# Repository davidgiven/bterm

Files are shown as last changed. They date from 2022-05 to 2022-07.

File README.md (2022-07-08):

bterm
=====

What?
-----

This is a set of firmware and hardware to turn a Brother WP-1 into a serial
terminal for a Raspberry Pi.

It consists of:

  - software to make a Brother bootable floppy containing a VT102-subset serial
	terminal

  - firmware for a PSoC5 CY8CKIT-049 based interface

  - a PCB which connects the Brother, CY8CKIT-049 and Raspberry Pi together

  - a 3D printable fascia which fits into the Brother's expansion slot

It also provides a MDA/Hercules/CGA-compatible video out connector which
reproduces what's on the Brother's screen.

Why?
----

Why not?

How?
----

So this is all so bespoke to my purposes that it's probably not going to be
very useful to anyone else. What documentation there is comes from the Youtube
series of videos I made while I developed this:

https://www.youtube.com/playlist?list=PLuQ2s_IbSWv5NDpc9Ew3BYDSF7siX9mNj

But here are some quick notes:

  - build the client software are write it to a floppy (you'll need zmac, ld80
	and fluxengine)

  - build the CY8CKIT-049 firmware and flash it with the Cypress development
	tools

  - get the PCB made and solder the connectors onto it

  - solder a 44-pin connector onto the unpopulated expansion breakout pads on
	the Brother motherboard

  - install Linux (or another OS of your choice) onto a Raspberry Pi, and
	configure out to use hardware handshaking on the main UART

  - plug everything together and attach the flyleads to the Brother CPU's /RD,
	/WR and /IOEN lines

  - ensure that there's a reset button and power switch connected to the
	interface board

  - switch everything on with Code+Q pressed on the Brother

...and then, if you're lucky, it might work.

If you are actually interested in trying this, best thing is to [file an
issue](https://github.com/davidgiven/bterm/issues/new/choose) and I'll see what
I can do to help. Or just send me an email (see below).

Who?
----

I am David Given, a.k.a. hjalfi in various places. Feel free to send me email
at [dg@cowlark.com](mailto:dg@cowlark.com). You may also [like to visit my
website](http://cowlark.com); there may or may not be something interesting
there.

License?
--------

Everything I wrote, which is nearly everything, is freely redistributable under
the terms of the simplified 2-clause BSD license. tl;dr: go nuts, just don't
claim you wrote it. See the `LICENSE` file for more details.

The one exception are the Raspberry Pi and CYC8KIT-049 footprints in the
`kicad-pcb` directory, which are by SnapEDA and licensed under a Creative
Commons Attribution-ShareAlike 4.0 International License (CC BY-SA) with Design
Exception 1.0. This exception essentially means that the CC BY-SA limitations
don't apply as they're being distributed as part of an aggregate design. [See
SnapEDA's page for
details.](https://support.snapeda.com/en/articles/2957815-what-is-the-design-exception-1-0)

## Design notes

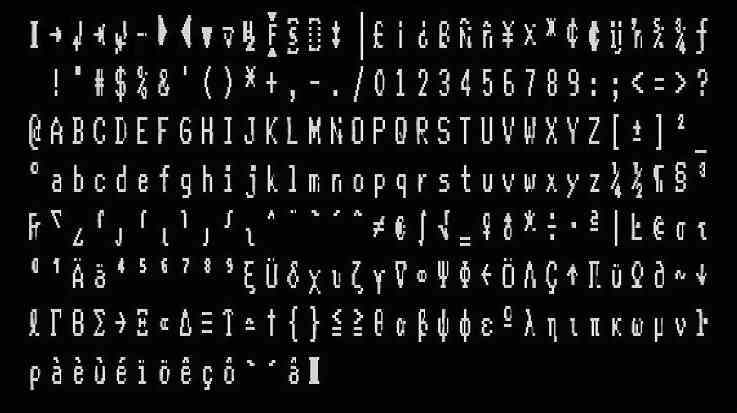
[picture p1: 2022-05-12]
client/font.jpg

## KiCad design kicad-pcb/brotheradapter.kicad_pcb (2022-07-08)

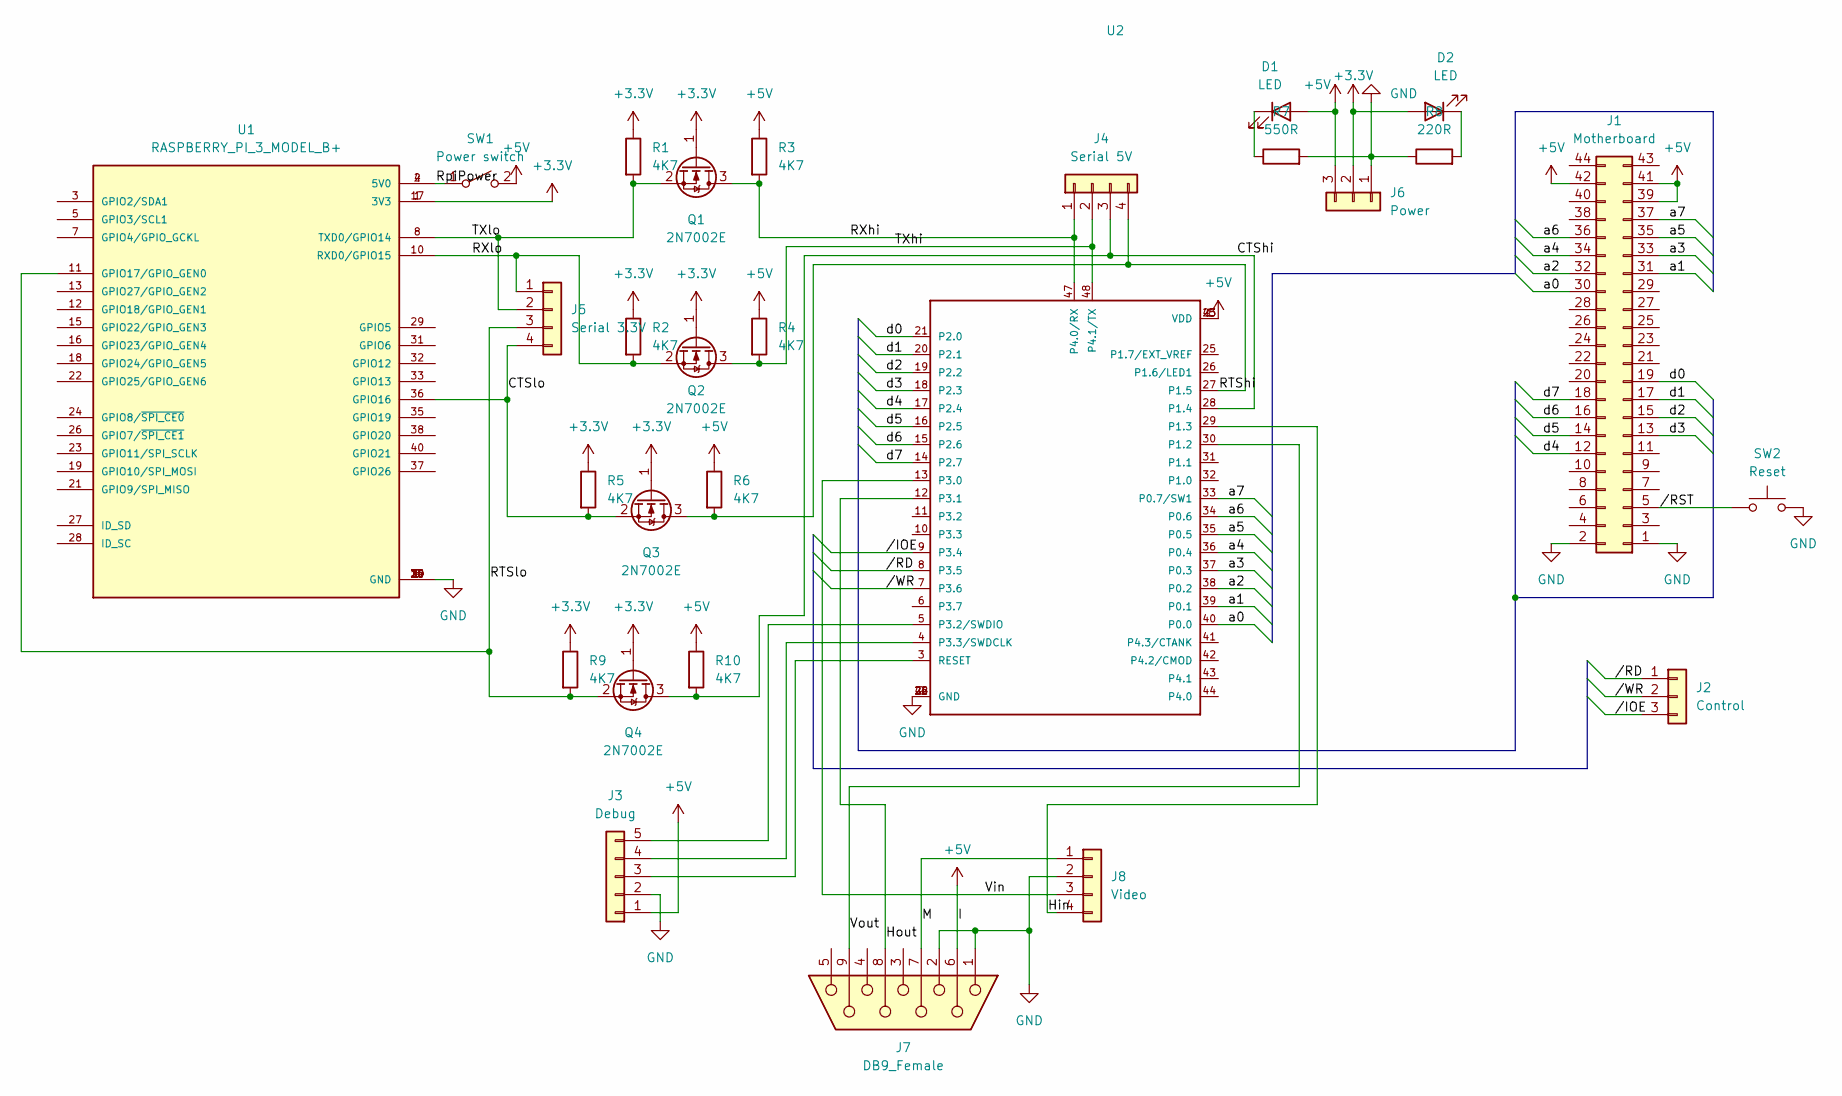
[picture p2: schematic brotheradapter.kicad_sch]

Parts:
D1, D2: LED; LED_0603_1608Metric
J1: Motherboard; PinHeader_2x22_P2.54mm_Vertical
J2: Control; PinSocket_1x03_P2.54mm_Vertical
J3: Debug; PinHeader_1x05_P2.54mm_Vertical
J4: Serial 5V; PinSocket_1x04_P2.54mm_Vertical
J5: Serial 3.3V; PinSocket_1x04_P2.54mm_Vertical
J6: Power; PinSocket_1x03_P2.54mm_Vertical
J7: DB9_Female; DSUB-9_Female_EdgeMount_P2.77mm
J8: Video; PinHeader_1x04_P2.54mm_Vertical
Q1, Q2, Q3, Q4: 2N7002E; SOT-23
R1, R2, R3, R4, R5, R6, R9, R10: 4K7; R_0603_1608Metric
R7: 550R; R_0603_1608Metric
R8: 220R; R_0603_1608Metric
SW1: Power switch; PinHeader_1x02_P2.54mm_Vertical
SW2: Reset; PinHeader_1x02_P2.54mm_Vertical
U1: RASPBERRY_PI_3_MODEL_B+; MODULE_RASPBERRY_PI_3_MODEL_B+; PARTREV 1.0
U2: CY8CKIT-049-42XX

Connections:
+3V3: D2.2 (A), J6.2, Q1.1 (G), Q2.1 (G), Q3.1 (G), Q4.1 (G), R1.1, R2.1, R5.1, R9.1, U1.1 (3V3), U1.17 (3V3)
+5V: D1.2 (A), J1.39, J1.41, J1.42, J3.1, J6.3, J7.6, R3.1, R4.1, R6.1, R10.1, SW1.2 (B), U2.1 (VDD), U2.23 (VDD), U2.45 (VDD)
/CTShi: J4.3, Q4.3 (D), R10.2, U2.28 (P1.4)
/CTSlo: J5.4, Q3.2 (S), R5.2, U1.36 (GPIO16)
/Hin: J8.4, U2.29 (P1.3)
/Hout: J7.8, U2.12 (P3.1)
/M: J7.7, J8.1
/RTSlo: J5.3, Q4.2 (S), R9.2, U1.11 (GPIO17/GPIO_GEN0)
/RXhi: J4.1, Q1.3 (D), R3.2, U2.47 (P4.0/RX)
/RXlo: J5.1, Q2.2 (S), R2.2, U1.10 (RXD0/GPIO15)
/RpiPower: SW1.1 (A), U1.2 (5V0), U1.4 (5V0)
/TXhi: J4.2, Q2.3 (D), R4.2, U2.48 (P4.1/TX)
/TXlo: J5.2, Q1.2 (S), R1.2, U1.8 (TXD0/GPIO14)
/Vin: J8.3, U2.13 (P3.0)
/Vout: J7.9, U2.30 (P1.2)
/a0: J1.30, U2.40 (P0.0)
/a1: J1.31, U2.39 (P0.1)
/a2: J1.32, U2.38 (P0.2)
/a3: J1.33, U2.37 (P0.3)
/a4: J1.34, U2.36 (P0.4)
/a5: J1.35, U2.35 (P0.5)
/a6: J1.36, U2.34 (P0.6)
/a7: J1.37, U2.33 (P0.7/SW1)
/d0: J1.19, U2.21 (P2.0)
/d1: J1.17, U2.20 (P2.1)
/d2: J1.15, U2.19 (P2.2)
/d3: J1.13, U2.18 (P2.3)
/d4: J1.12, U2.17 (P2.4)
/d5: J1.14, U2.16 (P2.5)
/d6: J1.16, U2.15 (P2.6)
/d7: J1.18, U2.14 (P2.7)
//IOE: J2.3, U2.9 (P3.4)
//RD: J2.1, U2.8 (P3.5)
//RST: J1.5, SW2.1
//WR: J2.2, U2.7 (P3.6)
GND: J1.1, J1.2, J3.2, J6.1, J7.1, J7.2, J8.2, R7.2, R8.1, SW2.2, U1.6 (GND), U1.9 (GND), U1.14 (GND), U1.20 (GND), U1.25 (GND), U1.30 (GND), U1.34 (GND), U1.39 (GND), U2.2 (GND), U2.22 (GND), U2.24 (GND), U2.46 (GND)
unnamed: D1.1 (K), R7.1
unnamed: D2.1 (K), R8.2
unnamed: J3.3, U2.3 (RESET)
unnamed: J3.4, U2.4 (P3.3/SWDCLK)
unnamed: J3.5, U2.5 (P3.2/SWDIO)
unnamed: J4.4, Q3.3 (D), R6.2, U2.27 (P1.5)

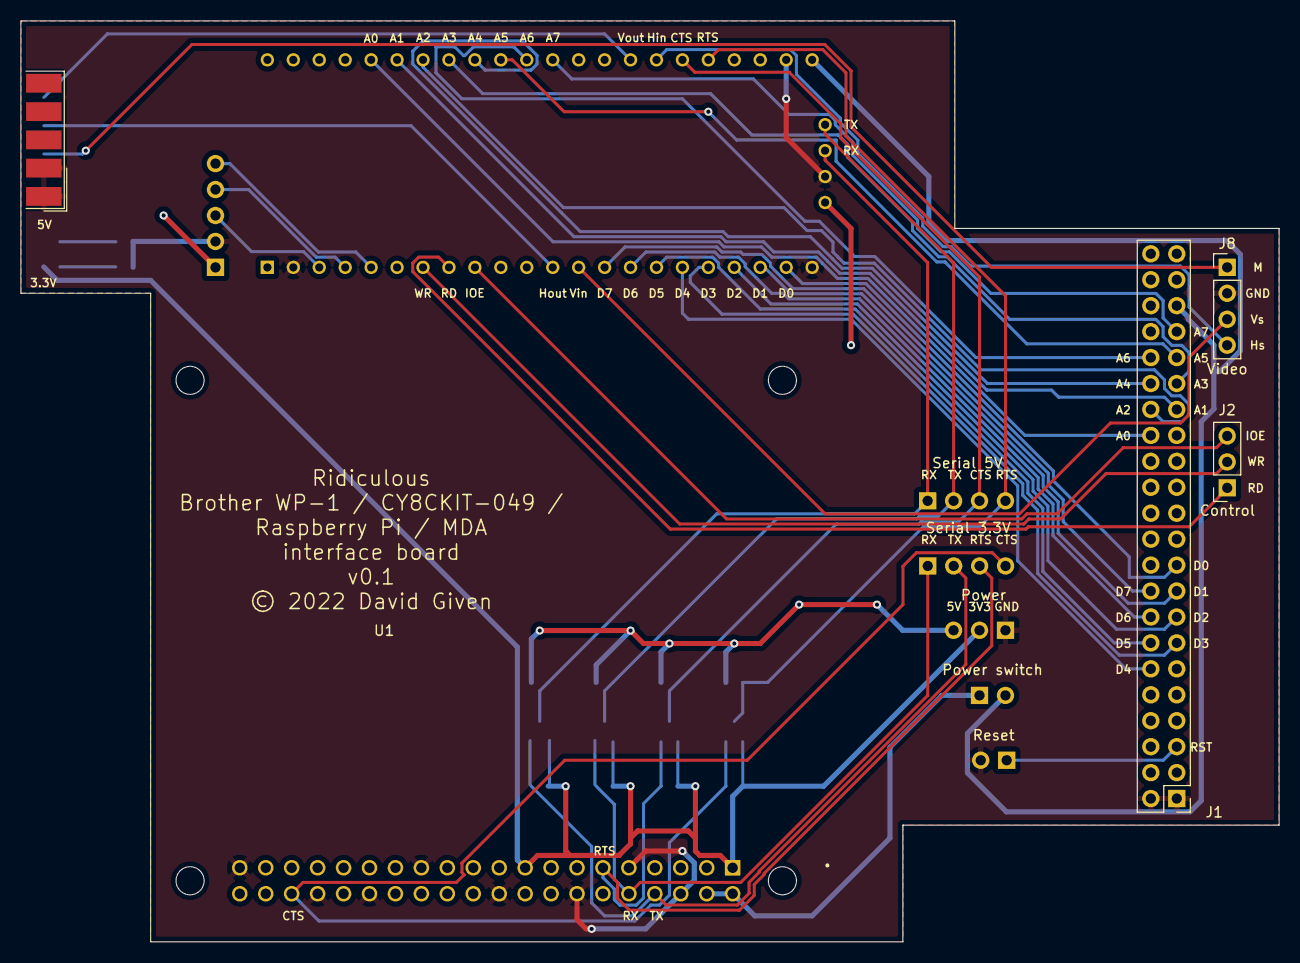
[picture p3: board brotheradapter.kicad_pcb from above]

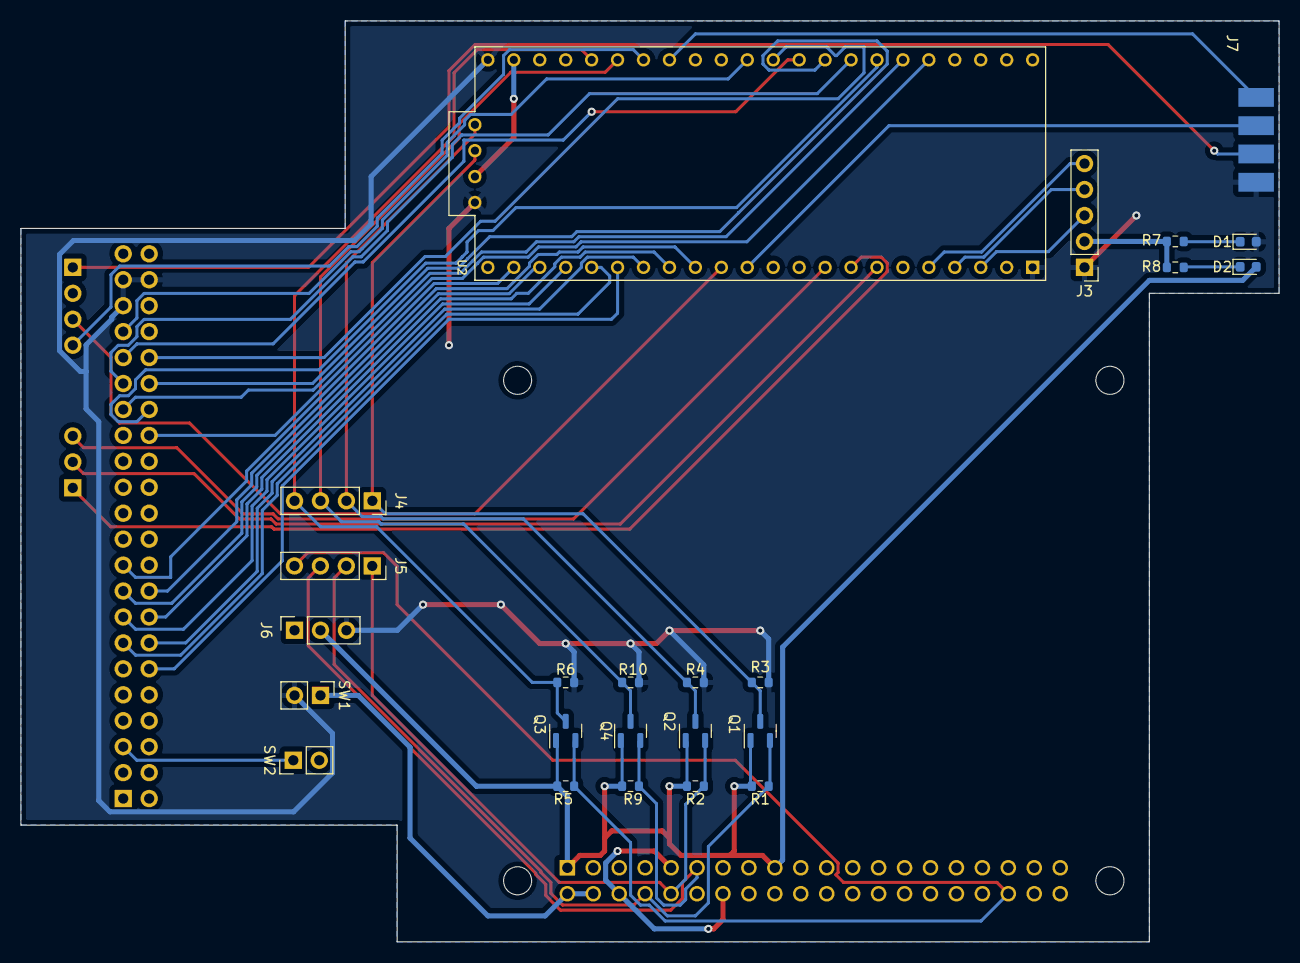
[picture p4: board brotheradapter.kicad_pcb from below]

Board: 2 copper layers, 123.2 x 90.2 mm, 28 parts (23 on the bottom side), 42 nets.

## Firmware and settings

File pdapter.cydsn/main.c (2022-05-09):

#include "project.h"
#include <stdint.h>
#include <stdbool.h>

enum
{
    RS_IDLE = 0, /* no data in buffer, no data pending */
    RS_READABLE, /* data in buffer */
    RS_DONE,     /* data has been read */
};

enum
{
    RA_DATA = (1<<0), /* data has been from buffer */
    RA_DONE = (1<<1), /* interface has been seen in RS_DONE */
};

enum
{
    WS_WRITABLE = 0, /* waiting for data in buffer */
    WS_WRITING,      /* data is being sent */
    WS_DONE,         /* data has been sent */
};

enum
{
    WA_DATA = (1<<2), /* data has been placed in the buffer */
    WA_DONE = (1<<3), /* interface has been seen in WS_DONE */
};

enum
{
    RESET = 128
};

static int read_state = RS_IDLE;
static int write_state = WS_WRITABLE;

int main(void)
{
    CyGlobalIntEnable; /* Enable global interrupts. */
    UART_Start();

    for(;;)
    {
        uint32_t ackbits = STATUS_REG1_Read();
        
        if (ackbits & RESET)
        {
            //UART_UartPutString("reset\r\n");
            read_state = RS_IDLE;
            write_state = WS_WRITABLE;
        }
        
        unsigned readBufferSize = UART_SpiUartGetRxBufferSize();
        switch (read_state)
        {
            case RS_IDLE:
            {
                if (readBufferSize > 0)
                {
                    uint32_t b = UART_UartGetByte();
                    CONTROL_REG0_Write(b & 0xff);
                    read_state = RS_READABLE;
                    //UART_UartPutString("RS_IDLE -> RS_READABLE\r\n");
                }                
                break;
            }
            
            case RS_READABLE:
            {
                if (ackbits & RA_DATA)
                {
                    //UART_UartPutString("RS_READABLE -> RS_DONE\r\n");
                    read_state = RS_DONE;
                }
                break;
            }
            
            case RS_DONE:
            {
                if (ackbits & RA_DONE)
                {
                    //UART_UartPutString("RS_DONE -> RS_IDLE\r\n");
                    read_state = RS_IDLE;
                }
                break;
            }
        }
        
        switch (write_state)
        {
            case WS_WRITABLE:
                if (ackbits & WA_DATA)
                {
                    write_state = WS_WRITING;
                    //UART_UartPutString("WS_WRITABLE -> WS_WRITING\r\n");
                }
                break;
            
            case WS_WRITING:
                if (UART_SpiUartGetTxBufferSize() < UART_TX_BUFFER_SIZE)
                {
                    uint8_t b = STATUS_REG0_Read();
                    UART_UartPutChar(b);
                    write_state = WS_DONE;
                    //UART_UartPutString("WS_WRITING -> WS_DONE\r\n");
                }
                break;
            
            case WS_DONE:
                if (ackbits & WA_DONE)
                {
                    write_state = WS_WRITABLE;
                    //UART_UartPutString("WS_DONE -> WS_WRITABLE\r\n");
                }
                break;
        }
        
        bool cts = readBufferSize < (UART_RX_BUFFER_SIZE / 2);
        CONTROL_REG1_Write(read_state | (write_state<<2) | (cts<<7));
    }
}

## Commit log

2022-05-08 Use DMA for updating the screen. Pack rows close together in video memory so that STRIDE == WIDTH.
2022-05-08 Remove the per-line dirty stuff, instead using a simple round-robin of updates with a three frame cycle. Seems to work much better and is simpler.
2022-05-08 Add CTS pin, hopefully.
2022-05-10 Add support for attributes. Use DMA for copying memory (almost) everywhere.
2022-05-12 Switch to four-page updates rather than three to remove the last bit of snow.
2022-05-23 Move the video pins to the right place for the bespoke PCB.
2022-05-24 Update some more pin assignments.
2022-05-26 Fix pin assignments, again.
2022-07-08 Fix OBO error when inserting and deleting lines.
2022-07-08 Add the kicad PCB.
    [brotheradapter.kicad_pcb, brotheradapter.kicad_sch]

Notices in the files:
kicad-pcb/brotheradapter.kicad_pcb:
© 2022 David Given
